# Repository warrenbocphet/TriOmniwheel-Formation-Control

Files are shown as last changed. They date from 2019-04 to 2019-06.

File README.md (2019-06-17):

# 3-OmniWheels-Rover-Platform
This project developed by students in [the University of Adelaide](https://ecms.adelaide.edu.au/electrical-electronic-engineering/) during the Summer Research project 2018-2019, which developed a 3WD  rover platform for autonomous multi-agent systems.

## Overview:
>The distributed system will contain multiple agents. Each agent can make its own decision. However, the four agents still need to communicate with each other about the velocity, the current position, the destination and the angle of the agent. This allows an agreement to be made to achieve the desired formation.

## Hardware setup:
Motor: 251RPM DC geared (43.7:1) motor w/ ecoder.

Encoder: 64 resolution => 2797 count per rotation.

Control board: Arduino Due for controlling, Arduino MKR1000 for WiFi communication.

## Example
### Simple case (user generated coordinate/path)
Real data feedback and put into simulation


Real demo. Noticed how the position of the rovers and the feedback position is not entirely the same. Overtime, the system introduce more and more error. Since the system is self guidance, there's no correction during performance.


### Formation control without collision avoidance
Generate path to form a triangle formation. Connected circle represent rover with radius, dash circle represent the safety distance (collision avoicedance is not implement in the GIF below).


The same triangle formation with different starting position. Noticed how the formation is rotated with these starting positions. The algorithm [1] does not try to get to a specific coordinate but rather a formation (i.e, a triangle, circle or any arbitrary topology).



### Formation control with collision avoidance
The collision avoidance will be explained further down, let's first have a look at the simulation and the result:

#### Hexagon




#### Triangle




#### X shape




#### Cross




#### Accumulating error (youtube link)
IMAGE ALT TEXT (https://www.youtube.com/watch?v=cinEIDQ7HyU "Accumulating error")

#### Reducing accumulating error by reducing the speed (youtube link)
IMAGE ALT TEXT (https://youtu.be/D_yIDlyvtvU "Reducing accumulating error by reducing the speed")

## Reference
[1] Fathian, Kaveh & Safaoui, Sleiman & Summers, Tyler & Gans, Nicholas. (2018). Robust Distributed Planar Formation Control for Higher-Order Holonomic and Nonholonomic Agents. Link: https://www.researchgate.net/publication/326696917_Robust_Distributed_Planar_Formation_Control_for_Higher-Order_Holonomic_and_Nonholonomic_Agents

The author's website: https://sites.google.com/view/kavehfathian/home?authuser=0

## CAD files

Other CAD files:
Rover platform v3.ipt

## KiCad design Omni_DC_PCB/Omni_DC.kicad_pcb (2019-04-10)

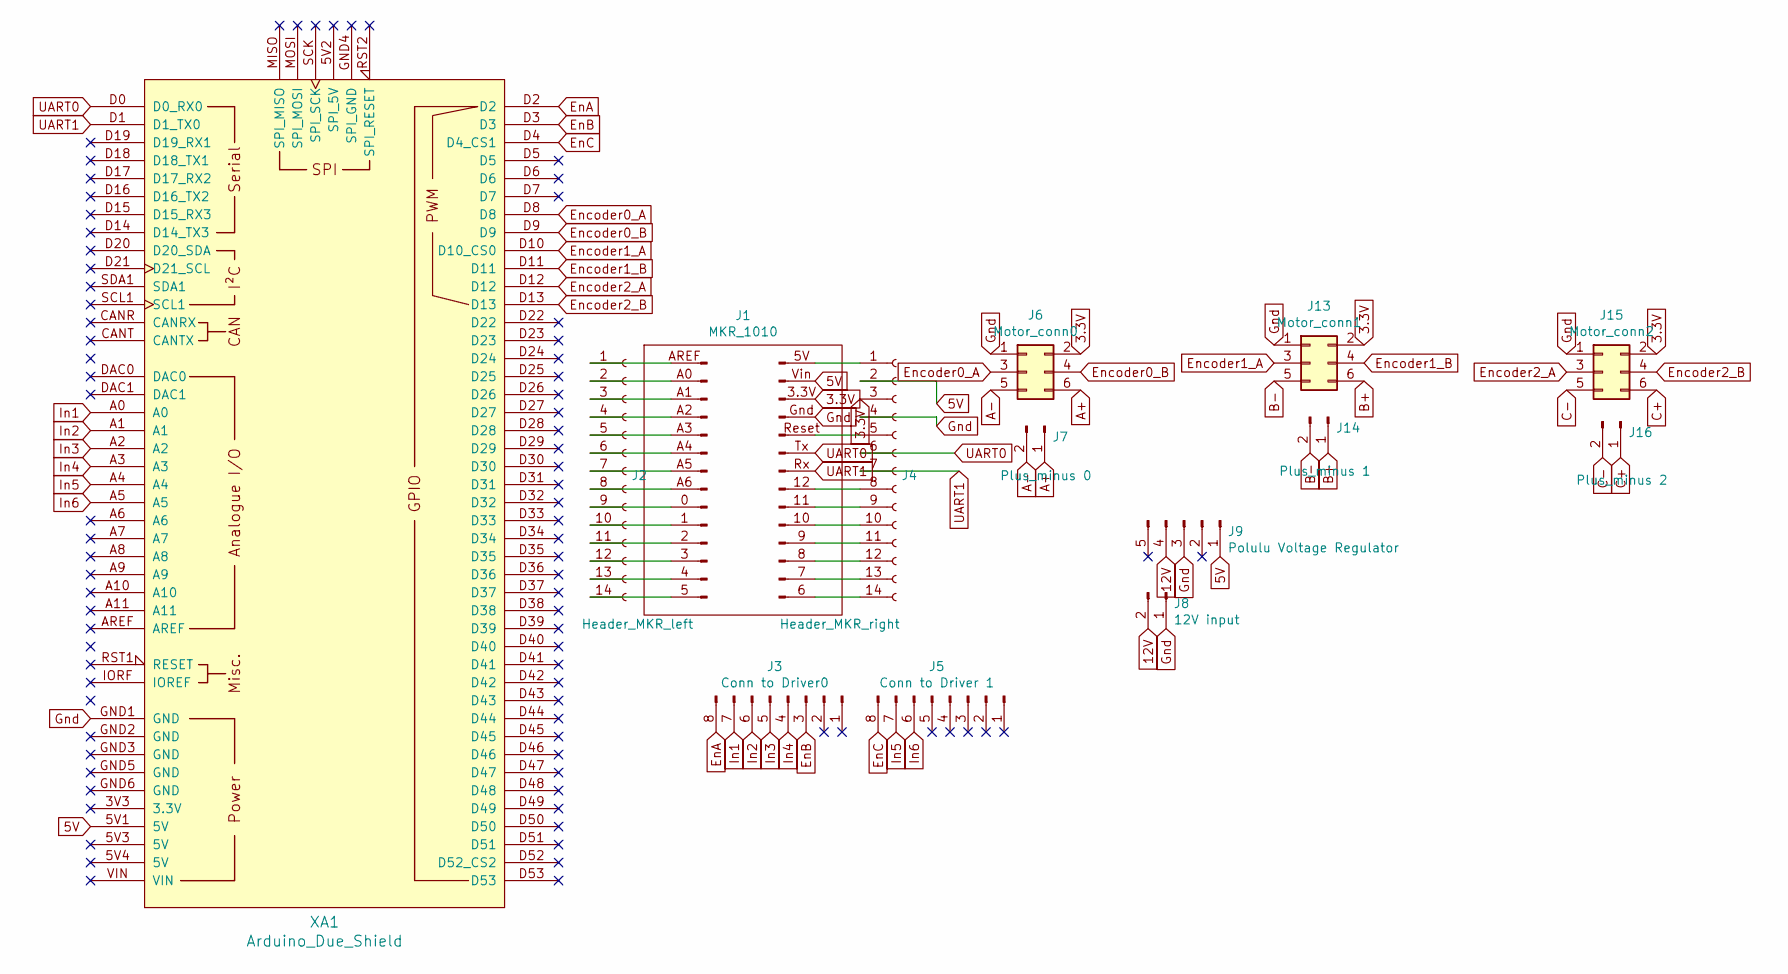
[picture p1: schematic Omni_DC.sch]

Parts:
J1: MKR_1010
J2: Header_MKR_left; PinHeader_1x14_P2.54mm_Vertical
J3: Conn to Driver0; PinHeader_1x08_P2.54mm_Vertical
J4: Header_MKR_right; PinHeader_1x14_P2.54mm_Vertical
J5: Conn to Driver 1; PinHeader_1x08_P2.54mm_Vertical
J6: Motor_conn0; PinHeader_2x03_P2.54mm_Vertical
J7: Plus_minus 0; PinHeader_1x02_P2.54mm_Vertical
J8: 12V input; PinHeader_1x02_P2.54mm_Vertical
J9: Polulu Voltage Regulator; PinHeader_1x05_P2.54mm_Vertical
J13: Motor_conn1; PinHeader_2x03_P2.54mm_Vertical
J14: Plus_minus 1; PinHeader_1x02_P2.54mm_Vertical
J15: Motor_conn2; PinHeader_2x03_P2.54mm_Vertical
J16: Plus_minus 2; PinHeader_1x02_P2.54mm_Vertical
XA1: Arduino_Due_Shield

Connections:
3.3V: J1.3.3V (Pin_3), J4.3, J6.2, J13.2, J15.2
5V: J1.Vin (Pin_2), J4.2, J9.1, XA1.5V1 (5V)
12V: J8.2, J9.4
A+: J6.6, J7.1
A-: J6.5, J7.2
B+: J13.6, J14.1
B-: J13.5, J14.2
C+: J15.6, J16.1
C-: J15.5, J16.2
EnA: J3.8, XA1.D2
EnB: J3.3, XA1.D3
EnC: J5.8, XA1.D4 (D4_CS1)
Encoder0_A: J6.3, XA1.D8
Encoder0_B: J6.4, XA1.D9
Encoder1_A: J13.3, XA1.D10 (D10_CS0)
Encoder1_B: J13.4, XA1.D11
Encoder2_A: J15.3, XA1.D12
Encoder2_B: J15.4, XA1.D13
Gnd: J1.Gnd (Pin_4), J4.4, J6.1, J8.1, J9.3, J13.1, J15.1, XA1.GND1 (GND)
In1: J3.7, XA1.A0
In2: J3.6, XA1.A1
In3: J3.5, XA1.A2
In4: J3.4, XA1.A3
In5: J5.7, XA1.A4
In6: J5.6, XA1.A5
unnamed: J1.0 (Pin_6), J2.9
unnamed: J1.1 (Pin_5), J2.10
unnamed: J1.2 (Pin_4), J2.11
unnamed: J1.3, J2.12
unnamed: J1.4 (Pin_2), J2.13
unnamed: J1.5 (Pin_1), J2.14
unnamed: J1.5V (1), J4.1
unnamed: J1.6 (Pin_14), J4.14
unnamed: J1.7 (Pin_13), J4.13
unnamed: J1.8 (Pin_12), J4.12
unnamed: J1.9 (Pin_11), J4.11
unnamed: J1.10, J4.10
unnamed: J1.11 (Pin_9), J4.9
unnamed: J1.12 (Pin_8), J4.8
unnamed: J1.A0 (Pin_13), J2.2
unnamed: J1.A1 (Pin_12), J2.3
unnamed: J1.A2 (Pin_11), J2.4
unnamed: J1.A3 (Pin_10), J2.5
unnamed: J1.A4 (Pin_9), J2.6
unnamed: J1.A5 (Pin_8), J2.7
unnamed: J1.A6 (Pin_7), J2.8
unnamed: J1.AREF (Pin_14), J2.1
unnamed: J1.Reset (Pin_5), J4.5
UART0: J1.Tx (Pin_6), J4.6, XA1.D0 (D0_RX0)
UART1: J1.Rx (Pin_7), J4.7, XA1.D1 (D1_TX0)

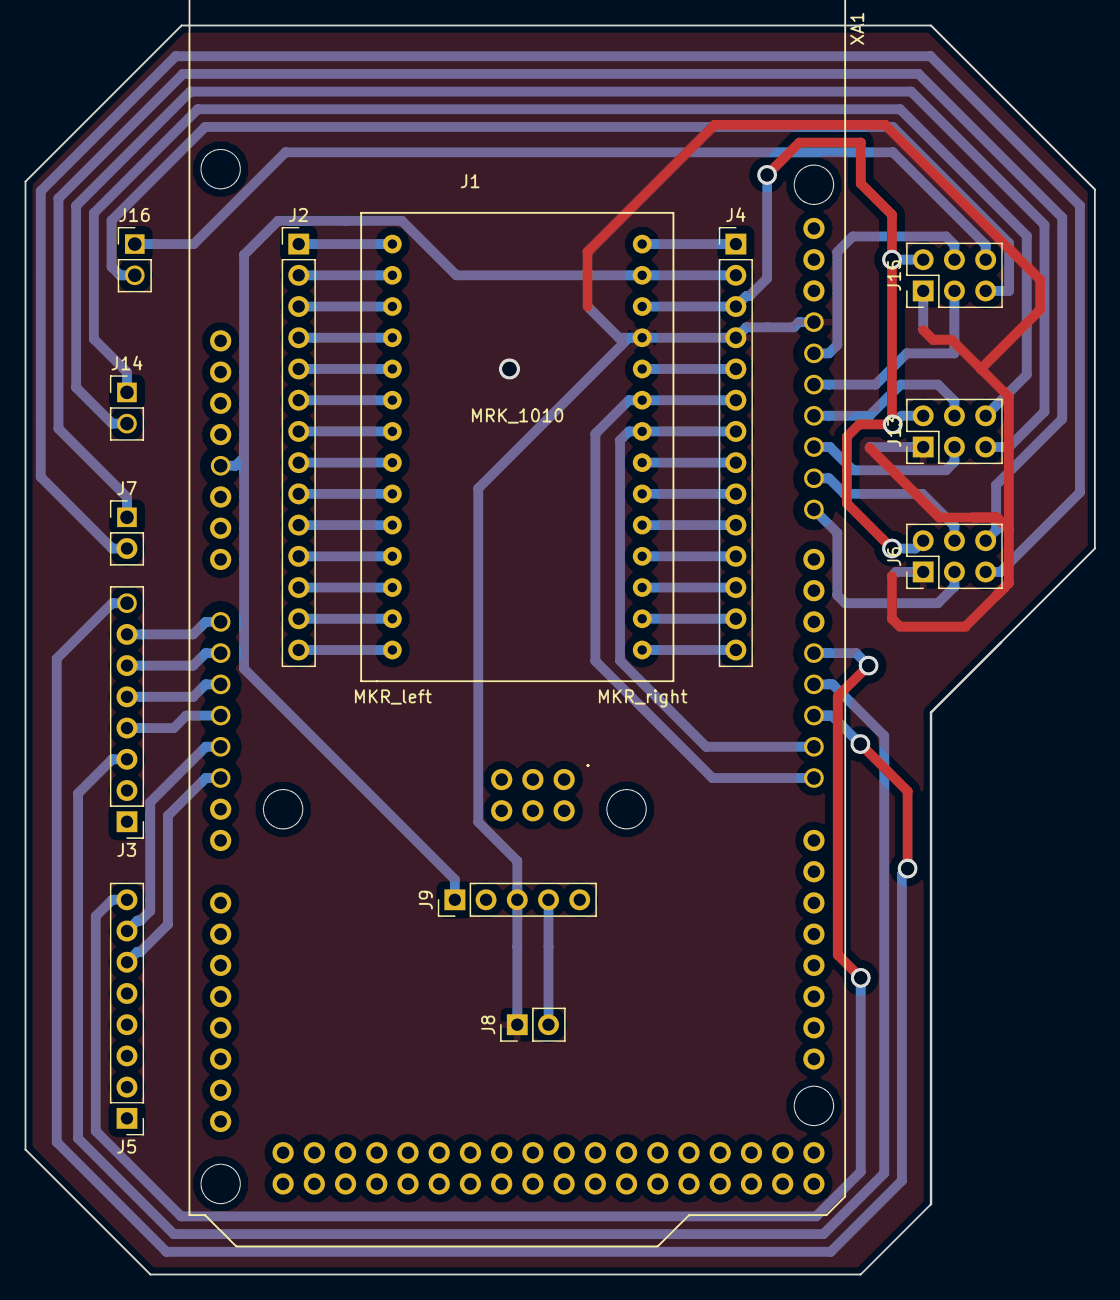
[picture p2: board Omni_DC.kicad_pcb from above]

Board: 2 copper layers, 87.0 x 101.6 mm, 14 parts (0 on the bottom side), 50 nets.

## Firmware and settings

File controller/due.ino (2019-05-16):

///////////////////////////// Library /////////////////////////////
#include <Encoder.h>
#include <PID_v1.h>

///////////////////////// communication /////////////////////
int twobytes1int(byte high, byte low)
{
  int number;
  int sign;

  sign = high >> 7;
  high = high << 1;
  high = high >> 1;

  number = low | (high << 8);
  number = number*(pow(-1, sign));
  return number;
}

struct byteInt  {
    int number;
    byte high;
    byte low;
};

struct byteInt xSend;
struct byteInt ySend;
struct byteInt phiSend;

void int2bytes(struct byteInt* number_fnc)  {
  int magnituteNumber;
  if (number_fnc->number >= 0)  {
    number_fnc->high = (number_fnc->number >> 8) & 0xFF;
    number_fnc->low = (number_fnc->number & 0xFF);
  } else {
    magnituteNumber = number_fnc->number * -1;
    number_fnc->high = (magnituteNumber >> 8) & 0xFF;
    number_fnc->high = number_fnc->high ^ 0x80;
    number_fnc->low = magnituteNumber & 0xFF;
  }
}

// Random variable
int i = 0, j = 0, k = 0, m = 0;
int a;
byte trash;
byte buf0[7];
byte buf1[7];
byte buf2[7];
byte buf3[7];

float targetX = 0.0, targetY = 0.0, targetPhi = 0.0;

///////////////////////////// DC motors /////////////////////////////
const int int1 = A0; // motor 0
const int int2 = A1;
const int enA = 2;
int pwm0;

const int int3 = A2; // motor 1
const int int4 = A3;
const int enB = 3;
int pwm1;

const int int5 = A4; // motor 2
const int int6 = A5;
const int enC = 4;
int pwm2;

float rover_radius = 13.7; // in cm
float wheel_radius = 5.22; // in cm

float constant_linearVelocity = (2*PI*wheel_radius);
float max_wheel_speed = (2*PI*wheel_radius)*2; // half rotation per second.

///////////////////////////// Encoder /////////////////////////////
Encoder enc0(8, 9);
Encoder enc1(10, 11);
Encoder enc2(12, 13);

double posPrevious0 = 0;
double posPrevious1 = 0;
double posPrevious2 = 0;

float displacement0 = 0;
float displacement1 = 0;
float displacement2 = 0;

float countPerRotation = 2797.0;

/////////////////////////// PID ////////////////////////////
struct motorPID_parameter {
  double Setpoint;
  double Input;
  double Output;
};

struct motorPID_parameter motor0;
struct motorPID_parameter motor1;
struct motorPID_parameter motor2;

//PID parameters
double Kp = 5.5, Ki = 17.5, Kd = 0.0;

////create PID instance

PID motorPID0(&motor0.Input, &motor0.Output, &motor0.Setpoint, Kp, Ki, Kd, DIRECT);
PID motorPID1(&motor1.Input, &motor1.Output, &motor1.Setpoint, Kp, Ki, Kd, DIRECT);
PID motorPID2(&motor2.Input, &motor2.Output, &motor2.Setpoint, Kp, Ki, Kd, DIRECT);

long posPreviousA = 0;
long posPreviousB = 0;
long posPreviousC = 0;

int displacementA = 0;
int displacementB = 0;
int displacementC = 0;

float speedA = 0.0, speedB = 0.0, speedC = 0.0;

////////////////// For keeping track of time ////////////////
unsigned long start0 = 0;
float elapsedTime0 = 0; // use as a timer to work with time_frame0
unsigned long start1 = 0;
float elapsedTime1 = 0;
unsigned long start2 = 0;
float elapsedTime2 = 0; // elapsedTime type should be float because use to calculate float data

int time_frame0 = 100;
int time_frame2 = 10;
//////////////////////// For integration /////////////////////////

float v0 = 0.0; // in cm/s
float v1 = 0.0;
float v2 = 0.0;

float v = 0.0;
float v_n = 0.0;
float w = 0.0;

float v_x = 0.0;
float v_y = 0.0;

float x = 0.0;
float y = 0.0;
float phi = 0.0;

float dx = 0.0;
float dy = 0.0;
float dphi = 0.0;

float speed0 = 0.0, speed1 = 0.0, speed2 = 0.0;

float time_limit = 1.0;

float phi_initial = PI;

float phi_t(float phi)
{
  return (-phi + phi_initial);
}

////////////////////////// setup and loop /////////////////////////
void setup() {
  Serial.begin(115200);

  pinMode(int1, OUTPUT);
  pinMode(int2, OUTPUT);
  pinMode(enA, OUTPUT);

  pinMode(int3, OUTPUT);
  pinMode(int4, OUTPUT);
  pinMode(enB, OUTPUT);

  pinMode(int5, OUTPUT);
  pinMode(int6, OUTPUT);
  pinMode(enC, OUTPUT);

  analogWrite(enA, 0);
  analogWrite(enB, 0);
  analogWrite(enC, 0);

  // PID0 initialize
  motorPID0.SetMode(AUTOMATIC);
  motorPID0.SetTunings(Kp, Ki, Kd);
  motorPID0.SetOutputLimits(-254,254);
  motorPID0.SetSampleTime(10);

  // PID1 initialize
  motorPID1.SetMode(AUTOMATIC);
  motorPID1.SetTunings(Kp, Ki, Kd);
  motorPID1.SetOutputLimits(-254,254);
  motorPID0.SetSampleTime(10);

  // PID2 initialize
  motorPID2.SetMode(AUTOMATIC);
  motorPID2.SetTunings(Kp, Ki, Kd);
  motorPID2.SetOutputLimits(-254,254);
  motorPID0.SetSampleTime(10);
  
  start0 = millis();
  start1 = millis();

  while (Serial.available())  {
    int trash;
    trash = Serial.read();
  }
}


void loop() {
  // Serial communication
  elapsedTime0 = millis() - start0;
  elapsedTime2 = millis() - start2;
  
  if (Serial.available() > 0) {
    a = Serial.read();
    if (a == 0) { // set target
      j = 0;
      while (j<6) {
        if (Serial.available()) {
          buf0[j] = Serial.read();
          j++;          
        }
      }

      targetX = twobytes1int(buf0[0], buf0[1]);
      targetY = -twobytes1int(buf0[2], buf0[3]);
      targetPhi = twobytes1int(buf0[4], buf0[5]);
      targetPhi = (targetPhi/180.0)*PI;
      
    } else if (a == 1)  { // ask coordinate
      xSend.number = (int) (x);
      ySend.number =  (int) (-y);
      phiSend.number = (int) ((phi/PI)*180.0); 

      int2bytes(&xSend);
      int2bytes(&ySend);
      int2bytes(&phiSend);

      buf1[0] = xSend.high;
      buf1[1] = xSend.low;
      buf1[2] = ySend.high;
      buf1[3] = ySend.low;
      buf1[4] = phiSend.high;
      buf1[5] = phiSend.low;
      for (i = 0; i<6; i++) {
        Serial.write(buf1[i]);
      }
    } else if (a == 2) { // set new starting point.
    	k = 0;
      while (k<6) {
        if (Serial.available()) {
          buf2[k] = Serial.read();
          k++;          
        }
      }

      x = twobytes1int(buf2[0], buf2[1]);
      y = -twobytes1int(buf2[2], buf2[3]);
      phi = twobytes1int(buf2[4], buf2[5]); // in degree/s
      phi = (phi/180.0)*PI; // in rad/s

      targetX = x;
      targetY = y;
      targetPhi = phi;
    } else if (a == 3)  { // set new current coordinate
      m = 0;
      while (m<6) {
        if (Serial.available()) {
          buf3[m] = Serial.read();
          m++;          
        }
      }

      x = twobytes1int(buf3[0], buf3[1]);
      y = -twobytes1int(buf3[2], buf3[3]);
      phi = twobytes1int(buf3[4], buf3[5]);
      phi = (phi/180.0)*PI;
    }

  }

  /////////////////////////// Controller /////////////////////////
  if (elapsedTime0 > time_frame0) // calculate required speed
  {
    start0 = millis();
    dx = targetX - x;
    dy = targetY - y;
    dphi = targetPhi - phi;

    // stopping condition
    if (abs(dx) < 1 && abs(dy) < 1 && abs(dphi) < 0.175)
    {
      // stop
      analogWrite(enA, 0);
      analogWrite(enB, 0);
      analogWrite(enC, 0);
      v0 = 0;
      v1 = 0;
      v2 = 0;

      displacement0 = (enc0.read() - posPrevious0); //in encoder count
      displacement1 = (enc1.read() - posPrevious1);
      displacement2 = (enc2.read() - posPrevious2);

      posPrevious0 = enc0.read(); //in encoder count
      posPrevious1 = enc1.read();
      posPrevious2 = enc2.read();

      speed0 = (displacement0 / countPerRotation) * (2 * PI * wheel_radius) / (elapsedTime0 / 1000.0); // convert to cm/s
      speed1 = (displacement1 / countPerRotation) * (2 * PI * wheel_radius) / (elapsedTime0 / 1000.0);
      speed2 = (displacement2 / countPerRotation) * (2 * PI * wheel_radius) / (elapsedTime0 / 1000.0);

      w = 1 / (3 * rover_radius) * (speed0 + speed1 + speed2);
      v = (sqrt(3) / 3) * (speed2 - speed0);
      v_n = 1 / 3.0 * (speed2 + speed0) - 2 / 3.0 * speed1;

      v_x = v * cos(phi_t(phi)) - v_n * sin(phi_t(phi));
      v_y = v * sin(phi_t(phi)) + v_n * cos(phi_t(phi));

      // calculate x, y phi
      x = x + v_x * elapsedTime0 / 1000.0;
      y = y + v_y * elapsedTime0 / 1000.0;
      phi = phi + w * elapsedTime0 / 1000.0;

    } else {

      if (abs(dx) < 10.0 && abs(dy) < 10.0)  {
        constant_linearVelocity = (2 * PI*wheel_radius)*0.5;
      } else {
        constant_linearVelocity = (2 * PI*wheel_radius);
      }

       time_limit = sqrt(dx*dx + dy*dy)/constant_linearVelocity;

      if (time_limit == 0)
      {
       time_limit = 1;
      }
      
      v_x = dx / time_limit;
      v_y = dy / time_limit;
      w = dphi / time_limit;

      if (abs(dx) < 2.0 && abs(dy) < 2.0 && abs(w) > (PI/2.0)) {
        w = PI/2.0*(w/abs(w));
      }

      /////////// Calculate require speed of 3 wheels //////////////

      // find v, v_n
      v = v_x * cos(phi_t(phi)) + v_y * sin(phi_t(phi));
      v_n = -v_x * sin(phi_t(phi)) + v_y * cos(phi_t(phi));

      // find v_0, v_1, v_2
      v0 = -v * sin(PI / 3) + v_n * cos(PI / 3) + w * rover_radius;
      v1 =              - v_n           + w * rover_radius;
      v2 =  v * sin(PI / 3) + v_n * cos(PI / 3) + w * rover_radius;

      // Speed limiting
      if (abs(v0) > max_wheel_speed || abs(v1) > max_wheel_speed || abs(v2) > max_wheel_speed) {
        // Find the highest speed
        float highest_speed = abs(v0);
        if (abs(highest_speed) < abs(v1)) {
          highest_speed = abs(v1);
        }

        if (abs(highest_speed) < abs(v2)) {
          highest_speed = abs(v2);
        }

        // Limit the speed to highest_speed
        v0 = v0/highest_speed*max_wheel_speed;
        v1 = v1/highest_speed*max_wheel_speed;
        v2 = v2/highest_speed*max_wheel_speed;

      }

      // PID control
      motor0.Setpoint = v0; // in cm/s
      motor1.Setpoint = v1;
      motor2.Setpoint = v2;

      ////////////////////////// Integration ////////////////////////

      // Get encoder data
      displacement0 = (enc0.read() - posPrevious0); //in encoder count
      displacement1 = (enc1.read() - posPrevious1);
      displacement2 = (enc2.read() - posPrevious2);

      posPrevious0 = enc0.read(); //in encoder count
      posPrevious1 = enc1.read();
      posPrevious2 = enc2.read();

      speed0 = (displacement0 / countPerRotation) * (2 * PI * wheel_radius) / (elapsedTime0 / 1000.0); // convert to cm/s
      speed1 = (displacement1 / countPerRotation) * (2 * PI * wheel_radius) / (elapsedTime0 / 1000.0);
      speed2 = (displacement2 / countPerRotation) * (2 * PI * wheel_radius) / (elapsedTime0 / 1000.0);

      motor0.Input = speed0; // in cm/s
      motor1.Input = speed1;
      motor2.Input = speed2;

      motorPID0.Compute();
      motorPID1.Compute();
      motorPID2.Compute();

      float pwm0 = motor0.Output;
      float pwm1 = motor1.Output;
      float pwm2 = motor2.Output;

      if (pwm0 > 0) {
        digitalWrite(int1, 1);
        digitalWrite(int2, 0);
        analogWrite(enA, pwm0);
      } else {
        digitalWrite(int1, 0);
        digitalWrite(int2, 1);
        analogWrite(enA, -pwm0);
      }

      if (pwm1 > 0) {
        digitalWrite(int3, 1);
        digitalWrite(int4, 0);
        analogWrite(enB, pwm1);

      } else {
        digitalWrite(int3, 0);
        digitalWrite(int4, 1);
        analogWrite(enB, -pwm1);
      }

      if (pwm2 > 0) {
        digitalWrite(int5, 1);
        digitalWrite(int6, 0);
        analogWrite(enC, pwm2);
      } else {
        digitalWrite(int5, 0);
        digitalWrite(int6, 1);
        analogWrite(enC, -pwm2);
      }

      // Done getting data, start integration
      // recalculating v_x, v_y and w

      w = 1 / (3 * rover_radius) * (speed0 + speed1 + speed2);
      v = (sqrt(3) / 3) * (speed2 - speed0);
      v_n = 1 / 3.0 * (speed2 + speed0) - 2 / 3.0 * speed1;

      v_x = v * cos(phi_t(phi)) - v_n * sin(phi_t(phi));
      v_y = v * sin(phi_t(phi)) + v_n * cos(phi_t(phi));

      // calculate x, y phi
      x = x + v_x * elapsedTime0 / 1000.0;
      y = y + v_y * elapsedTime0 / 1000.0;
      phi = phi + w * elapsedTime0 / 1000.0;
    }
  }

}

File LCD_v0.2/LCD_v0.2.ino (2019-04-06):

#include <U8glib.h>


/////////////////////////////////////////////////// LCD DISPLAY ///////////////////////////////////////////////////
///////////////////////////////////////////////////////////////////////////////////////////////////////////////////

//U8GLIB_NHD_C12864 u8g(13, 11, 10, 9, 8);  // SPI Com: SCK = 13, MOSI = 11, CS = 10, CD = 9, RST = 8
U8GLIB_NHD_C12864 u8g(9, 8, 7, 6);  // SPI Com: SCK = 9, MOSI = 8, CS = 7, CD = 6, RST = RESET

char charX[5];
char charY[5];
char charPhi[5];

char char_targetX[5];
char char_targetY[5];
char char_targetPhi[5];

char char_set_targetX[5];
char char_set_targetY[5];
char char_set_targetPhi[5];

int x = 0;
int y = 0;
int phi = 0;

int targetX = 0;
int targetY = 0;
int targetPhi = 0;

int set_targetX = 0;
int set_targetY = 0;
int set_targetPhi = 0;

void add_sign2string0()  {
  int x_fnc = x;
  int y_fnc = y;
  int phi_fnc = phi;

  if (x_fnc<0)  {
    charX[0] = 45;
  } else {
    charX[0] = 43;
  }

  if (y_fnc<0)  {
    charY[0] = 45;
  } else {
    charY[0] = 43;
  }

  if (phi_fnc<0)  {
    charPhi[0] = 45;
  } else {
    charPhi[0] = 43;
  }
}

void add_sign2string1()  {
  int targetX_fnc = targetX;
  int targetY_fnc = targetY;
  int targetPhi_fnc = targetPhi;

  if (targetX_fnc<0)  {
    char_targetX[0] = 45;
  } else {
    char_targetX[0] = 43;
  }

  if (targetY_fnc<0)  {
    char_targetY[0] = 45;
  } else {
    char_targetY[0] = 43;
  }

  if (targetPhi_fnc<0)  {
    char_targetPhi[0] = 45;
  } else {
    char_targetPhi[0] = 43;
  }
}

void add_sign2string2()  {
  int set_targetX_fnc = set_targetX;
  int set_targetY_fnc = set_targetY;
  int set_targetPhi_fnc = set_targetPhi;

  if (set_targetX_fnc<0)  {
    char_set_targetX[0] = 45;
  } else {
    char_set_targetX[0] = 43;
  }

  if (set_targetY_fnc<0)  {
    char_set_targetY[0] = 45;
  } else {
    char_set_targetY[0] = 43;
  }

  if (set_targetPhi_fnc<0)  {
    char_set_targetPhi[0] = 45;
  } else {
    char_set_targetPhi[0] = 43;
  }
}

void convert_int2string0() {
  int x_fnc = x;
  int y_fnc = y;
  int phi_fnc = phi;

  if (x_fnc<0)  {
    x_fnc = x_fnc * -1;
  }
  
  charX[1] = x_fnc/100 + 48;
  x_fnc = x_fnc - x_fnc/100*100;
  charX[2] = x_fnc/10 + 48;
  x_fnc = x_fnc - x_fnc/10*10;
  charX[3] = x_fnc + 48;
  charX[4] = '\0';    

  if (y_fnc<0)  {
    y_fnc = y_fnc * -1;
  }

  charY[1] = y_fnc/100 + 48;
  y_fnc = y_fnc - y_fnc/100*100;
  charY[2] = y_fnc/10 + 48;
  y_fnc = y_fnc - y_fnc/10*10;
  charY[3] = y_fnc + 48;
  charY[4] = '\0'; 

  if (phi_fnc<0)  {
    phi_fnc = phi_fnc * -1;
  }
  
  charPhi[1] = phi_fnc/100 + 48;
  phi_fnc = phi_fnc - phi_fnc/100*100;
  charPhi[2] = phi_fnc/10 + 48;
  phi_fnc = phi_fnc - phi_fnc/10*10;
  charPhi[3] = phi_fnc + 48;
  charPhi[4] = '\0'; 

}

void convert_int2string1() {
  int targetX_fnc = targetX;
  int targetY_fnc = targetY;
  int targetPhi_fnc = targetPhi;

  if (targetX_fnc<0)  {
    targetX_fnc = targetX_fnc * -1;
  }
  
  char_targetX[1] = targetX_fnc/100 + 48;
  targetX_fnc = targetX_fnc - targetX_fnc/100*100;
  char_targetX[2] = targetX_fnc/10 + 48;
  targetX_fnc = targetX_fnc - targetX_fnc/10*10;
  char_targetX[3] = targetX_fnc + 48;
  char_targetX[4] = '\0';    

  if (targetY_fnc<0)  {
    targetY_fnc = targetY_fnc * -1;
  }

  char_targetY[1] = targetY_fnc/100 + 48;
  targetY_fnc = targetY_fnc - targetY_fnc/100*100;
  char_targetY[2] = targetY_fnc/10 + 48;
  targetY_fnc = targetY_fnc - targetY_fnc/10*10;
  char_targetY[3] = targetY_fnc + 48;
  char_targetY[4] = '\0'; 

  if (targetPhi_fnc<0)  {
    targetPhi_fnc = targetPhi_fnc * -1;
  }
  
  char_targetPhi[1] = targetPhi_fnc/100 + 48;
  targetPhi_fnc = targetPhi_fnc - targetPhi_fnc/100*100;
  char_targetPhi[2] = targetPhi_fnc/10 + 48;
  targetPhi_fnc = targetPhi_fnc - targetPhi_fnc/10*10;
  char_targetPhi[3] = targetPhi_fnc + 48;
  char_targetPhi[4] = '\0'; 

}

void convert_int2string2() {
  int set_targetX_fnc = set_targetX;
  int set_targetY_fnc = set_targetY;
  int set_targetPhi_fnc = set_targetPhi;

  if (set_targetX_fnc<0)  {
    set_targetX_fnc = set_targetX_fnc * -1;
  }
  
  char_set_targetX[1] = set_targetX_fnc/100 + 48;
  set_targetX_fnc = set_targetX_fnc - set_targetX_fnc/100*100;
  char_set_targetX[2] = set_targetX_fnc/10 + 48;
  set_targetX_fnc = set_targetX_fnc - set_targetX_fnc/10*10;
  char_set_targetX[3] = set_targetX_fnc + 48;
  char_set_targetX[4] = '\0';    

  if (set_targetY_fnc<0)  {
    set_targetY_fnc = set_targetY_fnc * -1;
  }

  char_set_targetY[1] = set_targetY_fnc/100 + 48;
  set_targetY_fnc = set_targetY_fnc - set_targetY_fnc/100*100;
  char_set_targetY[2] = set_targetY_fnc/10 + 48;
  set_targetY_fnc = set_targetY_fnc - set_targetY_fnc/10*10;
  char_set_targetY[3] = set_targetY_fnc + 48;
  char_set_targetY[4] = '\0'; 

  if (set_targetPhi_fnc<0)  {
    set_targetPhi_fnc = set_targetPhi_fnc * -1;
  }
  
  char_set_targetPhi[1] = set_targetPhi_fnc/100 + 48;
  set_targetPhi_fnc = set_targetPhi_fnc - set_targetPhi_fnc/100*100;
  char_set_targetPhi[2] = set_targetPhi_fnc/10 + 48;
  set_targetPhi_fnc = set_targetPhi_fnc - set_targetPhi_fnc/10*10;
  char_set_targetPhi[3] = set_targetPhi_fnc + 48;
  char_set_targetPhi[4] = '\0'; 

}

void draw0(void) {
  // graphic commands to redraw the complete screen should be placed here  
  u8g.setFont(u8g_font_5x8);

  u8g.setFontPosTop();
  u8g.drawStr((64-u8g.getStrWidth("Current Pos"))/2, 0, "Current Pos");
  u8g.drawStr(5, 10, "X: ");
  u8g.drawStr(u8g.getStrWidth("X: ") + 1, 10, charX);
  u8g.drawStr(5, 20, "Y: ");
  u8g.drawStr(u8g.getStrWidth("Y: ") + 1, 20, charY);
  u8g.drawStr(5, 30, "Phi: ");
  u8g.drawStr(u8g.getStrWidth("Phi: ") + 1, 30, charPhi);

  u8g.drawStr((64-u8g.getStrWidth("Target"))/2 + 64, 0, "Target");
  u8g.drawStr(70, 10, "X: ");
  u8g.drawStr(u8g.getStrWidth("X: ") + 66, 10, char_targetX);
  u8g.drawStr(70, 20, "Y: ");
  u8g.drawStr(u8g.getStrWidth("Y: ") + 66, 20, char_targetY);
  u8g.drawStr(70, 30, "Phi: ");
  u8g.drawStr(u8g.getStrWidth("Phi: ") + 66, 30, char_targetPhi);

  u8g.drawStr((128 - u8g.getStrWidth("Run, Forrest, Run"))/2, 47, "Run, Forrest, Run!!");
  
  u8g.drawFrame(0,0,64,40);
  u8g.drawFrame(64,0,64,40);
  u8g.drawFrame(0,40,128,24);

}
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

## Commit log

2018-12-30 Add files via upload
    Arduino sketch that controls the speed of each wheel.
2018-12-30 Add files via upload
    The algorithm used to calculate the required speed of each wheel to reach the position and when to run those speed.
2018-12-30 Add files via upload
    API for the controller. Use to send and receive data through serial communication (UART) between Raspberry Pi and Arduino.
2018-12-30 Update roverScheduler.py
    Create an upper limitation on how big the angular velocity can be.
2019-01-07 Update roverScheduler.py
    Fix a bug where rover can't go to the same destination as the current destination.
2019-01-08 Update and rename simpleRover.ino to controllerArduino.ino
    Move all the controller part from RPI to Arduino.
2019-01-09 Update controllerArduino.ino
    Fix some minor bugs and add an ability to reset the current state of the rover back to [0, 0, 0].
2019-01-10 Add a function as requested by Vernon.
    The rover takes 1 more input (time) and rover only going to that point if the timer goes pass the input time.
2019-01-21 Update controllerArduino.ino
    Add IMU sensor
2019-01-22 Update controllerArduino.ino
    Added HPF to Gyro readings, LPF to Accel readings and complimentary filter for both afterwards.
2019-01-22 Update controllerArduino.ino
    Change how I calibrate the sensor
2019-01-27 Add files via upload
    Use to test how well the sensor feedback doing.
2019-01-28 Update test_feedback_speed.ino
    Test 3 wheels at the same time.
2019-01-29 Update test_feedback_speed.ino
    can change time frame more easily
2019-01-29 Add files via upload
    Run through Kalman Filter and then plot the data.
2019-01-29 Update test_feedback_speed.ino
    Remove complimentary filter.
2019-01-30 Update controllerArduino.ino
    Add Kalman Filtering.
2019-01-31 Update controllerArduino.ino
    Use IMU sensors feedback.
2019-01-31 Update controllerArduino.ino
    Bug fixes. (rover not able to keep track of Oxy)
2019-02-02 Add files via upload
    Add on board GUI.
2019-02-02 Rename test/plotData.py to testbench/test sensor data/plotData.py
2019-02-02 Rename test/test_feedback_speed.ino to testbench/test sensor data/test_feedback_speed.ino
2019-02-02 Rename testbench/test/getData.py to testbench/test sensor data/getData.py
2019-02-04 Add files via upload
    Laser cutting file for the platform
    [Rover platform v3.ipt]
2019-03-28 Update and rename controllerArduino.ino to due.ino
    Switch to a system with 2 different Arduino. This one is for the Due which directly control the motors.
2019-03-28 Update textGUI.py
    Improve socket communication.
2019-04-11 Update due.ino
    change PID parameter
2019-04-11 Update due.ino
    1. Fix a bug where "phi" data keep resetting back to 0 (because of typecasting)
    2. Increase accuracy by taking in account of slippage.
    [due.ino]
2019-04-11 Update and rename mkr1010.ino to mkr1000.ino
    Switch back to MKR1000 to save money.
2019-04-13 Update due.ino
    Give the ability to change the current coordinate (the rover won't move since the target is then equal to current coordinate).
    [due.ino]
2019-04-14 Update due.ino
    Add option to just set current coordinate to something else, rather than set both coordinate and target to something else.
2019-05-16 Update due.ino
    Fix a bug where it would flip the Y axis.
    [due.ino]
2019-05-16 Update mkr1000.ino
    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
    [mkr1000.ino]
2019-05-23 Add files via upload
    In a perfect world, I would test before commit but I got tired and just commit this to backup. There's no way this would work so don't even try.
2019-05-26 Update simulation.py
    Fix a bug where when you run path_generator.py, it would simulate the previous path, not the current one.
